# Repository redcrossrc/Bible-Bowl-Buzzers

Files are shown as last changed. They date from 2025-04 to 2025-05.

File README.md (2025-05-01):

# Bible-Bowl-Buzzers
Wiring, CAD, and code to build your own set of lockout buzzers.\
This was designed by EEOC Engineering with National Bible Bowl in mind.\
It incorporates as much of the functionality of Steve Kirkman's system as possible.\
Nearly all functionality is in code and CAD, so this design is extremely versatile.\
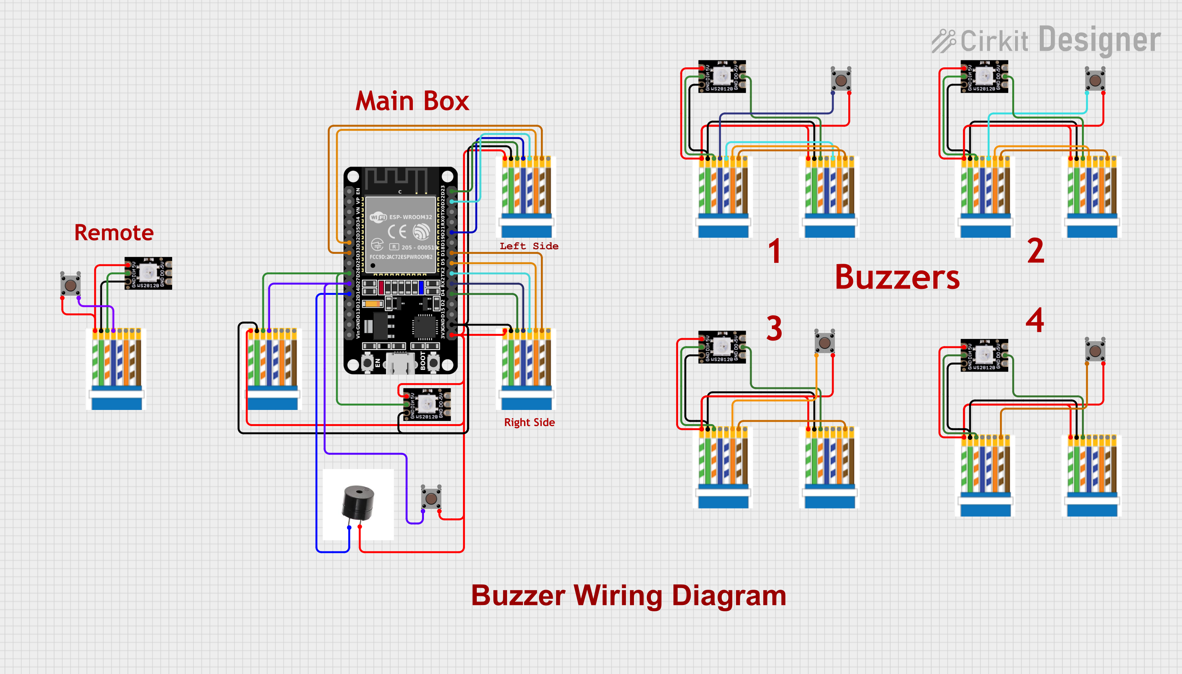
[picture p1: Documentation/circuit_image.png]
Wiring Diagram

Completed Set

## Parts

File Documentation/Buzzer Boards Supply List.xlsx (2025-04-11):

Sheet: Sheet1
Buzzer Boards Supply List
Part | Number | $ Cost | Source: | Notes:
ESP32-S3-WROOM | 1 | 6.99 | walmart.com (https://www.walmart.com/ip/ESP32-S3-DevKitC-1-Dual-Type-C-USB-ESP32-S3-WROOM-1-N8R8-Micropythons-S3-S7C3/2053065187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) | Must have 2 cores and enough data pins
Buttons | 12 | 8.99 | amazon.com (https://www.amazon.com/TWTADE-Momentary-Tactile-Button-12x12x12mm/dp/B07CG7VTGD) | Other buttons are available for lower prices or different tactile properties.
1m 60 IP30 WS2812B Lights | 1 | 6.15 | ebay.com (https://www.ebay.com/itm/334528146654?var=0&toolid=10044&customid=84a760ed032211302db40776edd361db) | Make sure they work with 3v.
Buzzer | 1 | 6.99 | amazon.com (https://www.amazon.com/mxuteuk-Electronic-Computers-Printers-Components/dp/B07VK1GJ9X) | Any buzzer or speaker will do.
3ft Ethernet Patch Cables | 10 | 13.43 | amazon.com (http://amazon.comw.amazon.com/Ethernet-Cable-Pack-Internet-Network/dp/B086BY3SN3) | If you are willing to sacrifice the ability to plug/unplug buzzers, you could
Female Ethernet Plugs | 24 | 14.99 | amazon.com (https://www.amazon.com/dp/B0BL6DRFTT?ref_=ppx_hzsearch_conn_dt_b_fed_asin_title_2&th=1)
5ft Ethernet cable for remote | 1 | 4.99 | amazon.com (https://www.amazon.com/Amazon-Basics-Ethernet-Gold-Plated-Connectors/dp/B00N2VILDM?s=industrial)
3D Printed Parts | 25 | 5 |  | PLA
Main Box | 1 |  |  | If you don't have a printer, you could buy stock boxes.
Remote Box | 1 |  |  | Better yet, find a makerspace or friend that has a printer.
Buzzer Boxes | 10 |  |  | Most people would be glad to print a few parts in their spare time.
Button Caps | 12
Total | 99 | 67.53
Other Parts
Solid Core Wire |  | 15.19 | amazon.com (https://www.amazon.com/TUOFENG-Hookup-Wires-6-Different-Colored/dp/B07TX6BX47)
Heat Shrink Tubing |  | 6.17 | amazon.com (https://www.amazon.com/Inch-XHF-Waterproof-Insulation-Wear-Resistant/dp/B0919GN3SX)

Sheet: Sheet2
Buzzer Boards Supply List
Part | Number | $ Cost | Source: | Notes:
ESP32-S3-WROOM | 10 | 56 | ebay.com (https://www.ebay.com/itm/385474648634?chn=ps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) | Must have 2 cores and enough data pins
6m 60 IP30 WS2812B Lights | 1 | 24.72 | ebay.com (https://www.ebay.com/itm/334528146654?var=0&toolid=10044&customid=84a760ed032211302db40776edd361db) | Make sure they work with 3v.
Buttons | 120 | 17.98 | amazon.com (https://www.amazon.com/TWTADE-Momentary-Tactile-Button-12x12x12mm/dp/B07CG7VTGD)
Buzzer | 10 | 6.99 | amazon.com (https://www.amazon.com/mxuteuk-Electronic-Computers-Printers-Components/dp/B07VK1GJ9X) | Any buzzer or speaker will do.
2ft Ethernet Patch Cables | 100 | 68.95 | ebay.com (https://www.ebay.com/itm/164080748791?campid=5338967983&toolid=10050)
Female Ethernet Plugs | 250 | 149.9 | amazon.com (https://www.amazon.com/dp/B0BL6DRFTT?ref_=ppx_hzsearch_conn_dt_b_fed_asin_title_2&th=1)
5ft Ethernet cable for Control | 10 | 34.77 | ebay.com (https://www.ebay.com/itm/304619400084?var=0&toolid=10044&customid=4792475d39061853e1b020b0aa6b61ef)
3D Printed Parts | 250 | 50 | amazon.com (https://www.amazon.com/SUNLU-PLA-Printer-Filament-1-75mm/dp/B0CN119CHL?th=1) | PLA
Main Box | 10 |  |  | If you don't have a printer, you could buy stock boxes.
Control Box | 10 |  |  | Better yet, find a makerspace or friend that has a printer.
Buzzer Boxes | 100 |  |  | Most people would be glad to print a few parts in their spare time.
Button Caps | 150
Total | 1021 | 409.31
Other Parts
Solid Core Wire |  | 15.19 | amazon.com (https://www.amazon.com/TUOFENG-Hookup-Wires-6-Different-Colored/dp/B07TX6BX47)
Heat Shrink Tubing |  | 6.17 | amazon.com (https://www.amazon.com/Inch-XHF-Waterproof-Insulation-Wear-Resistant/dp/B0919GN3SX)
Different Buttons | 120 | 39.6 | amazon.com (https://www.amazon.com/GATERON-KS-3X1-Milky-Brown-Full/dp/B0CW64FCGX?ref_=ast_sto_dp)

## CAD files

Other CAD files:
CAD/Buzzers 3.0 v83.f3d

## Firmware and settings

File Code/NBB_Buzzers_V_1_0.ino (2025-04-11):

#include "arduino_secrets.h"

// Header files
// Custom header file with neccesary variables, declarations and functions.
// These files should come with the code.
#include "Variables.h"

// Header files for OLED control
// These should be in the standard Arduino Libraries Database
#include <Wire.h>
#include <Adafruit_GFX.h>
#include <Adafruit_SSD1306.h>

// LED control header file
#include <Adafruit_NeoPixel.h>

// Declare the OLED display object using I2C
Adafruit_SSD1306 display(SCREEN_WIDTH, SCREEN_HEIGHT, &Wire, -1); // -1 because we're using I2C

// NeoPixel objects for left/right buzzers and the separate 3-LED strip
Adafruit_NeoPixel leftStrip(NUM_LEDS_PER_SIDE, LEFT_LED_PIN, NEO_GRB + NEO_KHZ800);
Adafruit_NeoPixel rightStrip(NUM_LEDS_PER_SIDE, RIGHT_LED_PIN, NEO_GRB + NEO_KHZ800);
Adafruit_NeoPixel boxStrip(3, BOX_STRIP_PIN, NEO_GRB + NEO_KHZ800);

void setup() {
  // Initialize the Wire library with custom SDA and SCL pins
  Wire.begin(sdaPin, sclPin);

  // Initialize the display with SSD1306_SWITCHCAPVCC and the correct I2C address
  display.begin(SSD1306_SWITCHCAPVCC, OLED_ADDR);
  // Clear the display buffer
  display.clearDisplay();

  // Set text size and color
  display.setTextSize(1); // Adjust text size
  display.setTextColor(SSD1306_WHITE); // Set text color to white
  
  PrintCenteredText("YELLOW", defaultMessage);

  // Initialize NeoPixel strips
  leftStrip.begin();
  rightStrip.begin();
  boxStrip.begin();

  for (int i = 0; i < buttonCount; i++) {  // This sets all buzzer button pins as inputs with a pulldown resistor
    pinMode(buttonPins[i], INPUT_PULLDOWN);
  }
  
  for (int i = 0; i < optionCount; i++) {  // This sets all option button pins as inputs with a pulldown resistor
    pinMode(optionPins[i], INPUT_PULLDOWN);
  }
  
  pinMode(buzzerPin, OUTPUT);              // This sets the pin for the passive buzzer that makes the beep sound as an output

  clearLEDs();
  
  // Start the FreeRTOS task on core 0 to run control()
  xTaskCreatePinnedToCore(
    ControlTask,           // Function to run
    "Control Task",        // Task name
    2048,                  // Stack size
    NULL,                  // Parameters
    1,                     // Task priority
    NULL,                  // Task handle
    0                      // Run on core 0
  );
  
  // Start the FreeRTOS task on core 1 to run buzzerLoop()
  xTaskCreatePinnedToCore(
    BuzzerTask,            // Function to run
    "Buzzer Task",         // Task name
    2048,                  // Stack size
    NULL,                  // Parameters
    1,                     // Task priority
    NULL,                  // Task handle
    1                      // Run on core 1
  );

}

void loop(){ // Empty Loop. Arduino will not compile without loop(), because stupidity.
  // I guess I could use this for something, but it makes more sense to name my functions myself.
}

void ControlTask(void *pvParameters) {
  while (true) {
    Control();       // Continuously run Control in one task
    vTaskDelay(10);  // Small delay to yield control
  }
}

void BuzzerTask(void *pvParameters) {
  while (true) {
    BuzzerLoop();  // Continuously run BuzzerLoop in one task
    vTaskDelay(10);  // Small delay to yield control
  }
}

void BuzzerLoop() {
  if (buzzerPressed) {
    tone(buzzerPin, 1500, 500);  // Short beep
    startTime = millis();
    baseIndex = (whichBuzzer) * BUZZER_LEDS;
    totalTime = BUZZER_LEDS * FADE_TIME;
    redTriggered = false;
    // Set up for swipe effect
    swipeEffectStarted = true;

    BlueScreen();                // Turn the entire blue part of the OLED on

    // Only proceed with animation if buzzerPressed is still true
    // This loop will keep core 1 occupied until buzzerPressed becomes false,
    // so the above two commands only run once each time the buzzer is pressed
    while (buzzerPressed) {
      elapsed = millis() - startTime;
      if (millis() - startTime < totalTime) {
        PlayAnimationWithBuzzer();
      }
      if (millis() - startTime < 3000) {
        ThreeSeconds();          // Run the 3-second wipe animation on the OLED
      }
      else {
        PlayAnimationWithBuzzer();
        PrintCenteredText("BLUE", "3 SECONDS");
      }
    // PrintCenteredText("YELLOW", String(scoreL) + " - " + String(scoreR)); // For scorekeeping
    PrintCenteredText("YELLOW", defaultMessage); // If not scorekeeping
    }
  }
  for (whichBuzzer = 0; whichBuzzer < buttonCount; whichBuzzer++) { // Check all buzzer buttons
    if (digitalRead(buttonPins[whichBuzzer]) == HIGH) {
      buzzerPressed = true; // If one has been pressed, save that info.
      if (whichBuzzer <= 4) {
        whichSide = leftSide;
      }    
      else {
        whichSide = rightSide;
        whichBuzzer -= 5;
      }
      return;
    }
  }
}

void Control() {                      // Checks for any control (clear, plus, minus, bonus) button to be pressed
  if (digitalRead(clearOP) == HIGH) { // Check for clear button
    buzzerPressed = false;            // Pass the buzzerPressed variable to core 1
    display.clearDisplay();
    clearLEDs();
  }
//  if (digitalRead(plusPin) == HIGH) { // Check if +5 button is pressed
//    AddPoints();
//  }
}

void BlueScreen() {   
  // Fill the blue section (rows 16-63) with blue (The call is "...WHITE"
  // because the code doesn't know the difference between a black-white OLED
  // and a black-blue OLED.)
  display.fillRect(0, 16, SCREEN_WIDTH, 48, SSD1306_WHITE);
  display.display();
}

void ThreeSeconds() {
  // Only run the swipe effect once
  if (swipeEffectStarted) {
    // Get the current time and calculate the elapsed time since the effect started
    unsigned long currentTime = millis();
    unsigned long elapsedTime = currentTime - startTime;

    // Ensure the swipe effect lasts for 3 seconds (3000 milliseconds)
    if (elapsedTime < 3000) {
      // Calculate the percentage of progress for the swipe effect
      float progress = float(elapsedTime) / 3000.0; // Value between 0 and 1
      
      // Calculate how much of the blue portion should be revealed
      int swipeHeight = int(progress * BLUE_PORTION_HEIGHT); // From 0 to full height

      // Clear the blue portion gradually (swipe effect)
      display.fillRect(0, BLUE_PORTION_TOP, SCREEN_WIDTH, swipeHeight, SSD1306_BLACK); // Use SSD1306_BLUE or your custom blue color

      // Print some text during the effect
      display.setCursor(10, SCREEN_HEIGHT - 10); // Place it at the bottom

      // Update the display to reflect the changes
      display.display();
    }
    else {
      // After 3 seconds, end the swipe effect
      swipeEffectStarted = false;
      // Finalize the blue portion (just in case)
      display.fillRect(0, BLUE_PORTION_TOP, SCREEN_WIDTH, BLUE_PORTION_HEIGHT, SSD1306_BLACK);
      // Ensure the text stays visible
      display.display();
    }
  }
}

// Function to print centered text on the OLED screen
void PrintCenteredText(String color, String text) {
  int textWidth = text.length() * 6; // Each character is 6 pixels wide in the default font
  int x, y;

  // Determine which section (yellow or blue) to clear and where to position the text
  if (color == "YELLOW") {
    // Clear the yellow portion (top 16 pixels)
    display.fillRect(0, 0, SCREEN_WIDTH, 16, BLACK); // Clear the yellow section

    // Center the text in the yellow section (y = 0 to 15)
    x = (SCREEN_WIDTH - textWidth) / 2; // Horizontal center
    y = (16 - 8) / 2; // Vertical center (16 pixels height, 8 pixel height font)
    
    display.setTextColor(SSD1306_WHITE); // Set text color to white (yellow section)
  } else if (color == "BLUE") {
    // Clear the blue portion (bottom 48 pixels)
    display.fillRect(0, 16, SCREEN_WIDTH, 48, BLACK); // Clear the blue section

    // Center the text in the blue section (y = 16 to 63)
    x = (SCREEN_WIDTH - textWidth) / 2; // Horizontal center
    y = 16 + (48 - 8) / 2; // Vertical center (48 pixels height, 8 pixel height font)
    
    display.setTextColor(SSD1306_WHITE); // Set text color to white (blue section)
  } else {
    return; // Invalid color input
  }

  // Print the text on the screen
  display.setCursor(x, y);
  display.print(text);
  display.display();
}

void AddPoints() {
  PrintCenteredText("YELLOW", "5 Points Added");
  score[whichBuzzer] += 5;
  delay(10);
}

void PlayAnimationWithBuzzer() {
  Adafruit_NeoPixel *animStrip = (whichSide == 0) ? &leftStrip : &rightStrip;
  totalTime = BUZZER_LEDS * FADE_TIME;
  
  if (!redTriggered && elapsed >= FADE_TIME) {
    redTriggered = true;
    setAllBuzzersToRed();
    // Update animated buzzer LEDs:
    for (int i = 0; i < BUZZER_LEDS; i++) {
      int t = elapsed - i * FADE_TIME;
      animStrip->setPixelColor(baseIndex + i, animColor(t));
    }
  }

  if (millis() - startTime >= totalTime) {
    // After animation, set animated buzzer and 3-LED strip to blue.
    for (int i = 0; i < BUZZER_LEDS; i++)
      animStrip->setPixelColor(baseIndex + i, animStrip->Color(0, 0, 200));
    for (int i = 0; i < 3; i++)
      boxStrip.setPixelColor(i, boxStrip.Color(0, 0, 200));
      animStrip->show();
      boxStrip.show();
    return;
  }

  // Update animated buzzer LEDs:
  for (int i = 0; i < BUZZER_LEDS; i++) {
    int t = elapsed - i * FADE_TIME;
    animStrip->setPixelColor(baseIndex + i, animColor(t));
  }
  // Update the separate 3-LED strip:
  for (int i = 0; i < 3; i++) {
    int t = elapsed - i * FADE_TIME;
    boxStrip.setPixelColor(i, animColor(t));
  }
  animStrip->show();
  boxStrip.show();
}

// Clear LED animation function
void clearLEDs() {
  // 1. Wipe back to blank (off) with delay every 3 LEDs
  for (int i = NUM_LEDS_PER_SIDE - 1; i >= 0; i--) {
    if (i % 3 == 2 && i != NUM_LEDS_PER_SIDE - 1) {
      delay(150);  // Delay every 3 LEDs to match the spreading effect
    }
    leftStrip.setPixelColor(i, leftStrip.Color(Color_Left));  // Purple
    rightStrip.setPixelColor(i, rightStrip.Color(Color_Right));  // Orange
    leftStrip.show();
    rightStrip.show();
    delay(25);  // Small delay for the wipe effect
  }

  // 2. Box LED strip turns white and wipes from the middle to blank
  for (int i = 0; i < 3; i++) {
    boxStrip.setPixelColor(i, boxStrip.Color(255, 255, 255));  // White
    boxStrip.show();
    delay(100);  // Wipe effect from left to right
  }

  // Final state: All LEDs stay purple and orange, 3-LED strip is cleared
  for (int i = 0; i < NUM_LEDS_PER_SIDE; i++) {
    leftStrip.setPixelColor(i, leftStrip.Color(Color_Left));  // Purple
    rightStrip.setPixelColor(i, rightStrip.Color(Color_Right));  // Orange
  }

  leftStrip.show();
  rightStrip.show();
}

// Sets all buzzers (including the animated one) to red for both sides.
void setAllBuzzersToRed() {
  // Set left side buzzers to red
  for (int i = 0; i < NUM_LEDS_PER_SIDE; i++) {
    leftStrip.setPixelColor(i, leftStrip.Color(255, 0, 0));  // Red
  }
  
  // Set right side buzzers to red
  for (int i = 0; i < NUM_LEDS_PER_SIDE; i++) {
    rightStrip.setPixelColor(i, rightStrip.Color(255, 0, 0));  // Red
  }

  leftStrip.show();
  rightStrip.show();
}

// Sets default colors: left buzzers violet, right buzzers orange.
void setDefaultColors() {
  for (int i = 0; i < NUM_LEDS_PER_SIDE; i++) {
    leftStrip.setPixelColor(i, leftStrip.Color(Color_Left));  // Violet
    rightStrip.setPixelColor(i, rightStrip.Color(Color_Right));  // Orange
  }
  leftStrip.show();
  rightStrip.show();
}

// Returns the animation color based on time offset t (ms):
// t < 0: solid green; 0 <= t < FADE_TIME: fade green->red; t >= FADE_TIME: off.
uint32_t animColor(int t) {
  if (t < 0) return leftStrip.Color(0, 255, 0);
  if (t < FADE_TIME) {
    float p = (float)t / FADE_TIME;
    return leftStrip.Color(p * 255, (1.0 - p) * 255, 0);
  }
  return leftStrip.Color(0, 0, 0);
}

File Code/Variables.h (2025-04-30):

// Left side buzzer pin numbers
const int anaBP = 21;
const int nathanaelBP = 22;
const int juniorTerroristBP = 15;
const int popoBP = 13;

// Right side buzzer pin numbers
const int tylerBP = 16;
const int kolbyBP = 17;
const int jkroppBP = 14; // Pin 5 is cursed.
const int shishiBP = 18;

// Buzzer pin array for digitalRead
const int buttonPins[] = {
anaBP, nathanaelBP, juniorTerroristBP, popoBP,
tylerBP, kolbyBP, jkroppBP, shishiBP
};
const int buttonCount = sizeof(buttonPins) / sizeof(buttonPins[0]);

bool buzzerPressed = false; // State variable to pass between cores

int whichBuzzer;

// Option Pins
const int clearOP = 27;   // Clear button on option
const int buzzerPin = 32;  // Passive buzzer for beep sound

#define LEFT_LED_PIN       23
#define RIGHT_LED_PIN      4
#define BOX_STRIP_PIN      26
#define NUM_LEDS_PER_SIDE  15  // 5 buzzers * 3 LEDs per buzzer
#define BUZZER_LEDS        3
#define COUNT_TIME         3.5
#define FADE_TIME          1000  // ms per LED transition
#define Color_Right        150, 0, 125
#define Color_Left         255, 98, 0
#define CLEAR_COLOR        0, 0, 255
#define OPTION_COLOR       0, 213, 255

#define LED_BRIGHTNESS     255

const int leftSide = 0;
const int rightSide = 1;
int whichSide;

unsigned long startTime;
unsigned long elapsed;
int totalTime = BUZZER_LEDS * FADE_TIME;
int baseIndex;
bool redTriggered;

// Variable to alternate tie-breaker results fairly
int lastTieBreakerWinner = -1;  // -1 = none yet, 0 = left, 1 = right

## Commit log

2025-02-03 Rename Buzzer Boards Supply List.xlsx to Documentation/Buzzer Boards Supply List.xlsx
    [Buzzer Boards Supply List.xlsx]
2025-02-03 Create ESP32-S3-WROOM
2025-02-03 Update README.md
    Add wiring diagram v1.0
2025-02-12 Update Supply List
    [Buzzer Boards Supply List.xlsx]
2025-04-11 4/11/25 Supply List Update
    [Buzzer Boards Supply List.xlsx]
2025-04-11 Update Circuit Images
    Add SVG format, Incorporate ethernet jacks
2025-04-11 Upload Fusion Source CAD
2025-04-11 Buzzers 2.0 v76.f3d to CAD/Buzzers 2.0 v76.f3d
    [Buzzers 2.0 v76.f3d]
2025-04-30 Upload newest CAD
    [Buzzers 3.0 v83.f3d]
2025-04-30 Remove old CAD
    [Buzzers 2.0 v76.f3d]
2025-04-30 Update Wiring Diagram
